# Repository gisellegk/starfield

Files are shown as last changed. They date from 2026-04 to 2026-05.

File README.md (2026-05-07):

# Starfield
May the force be with you

Arduino Libraries:
- [kriswiner/LP5036](https://github.com/kriswiner/LP5036/tree/master)
- [JackDaviesDesign/Pimoroni-11x7-LED-Matrix-Arduino](https://github.com/JackDaviesDesign/Pimoroni-11x7-LED-Matrix-Arduino)

Font:
- [Star Jedi](https://www.dafont.com/star-jedi.font)

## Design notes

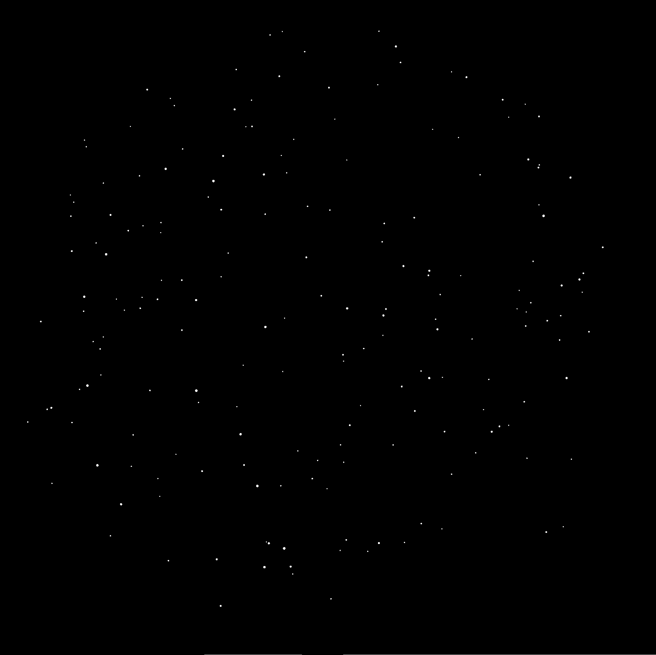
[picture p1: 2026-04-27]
stellarium-sc/dim_stars.png

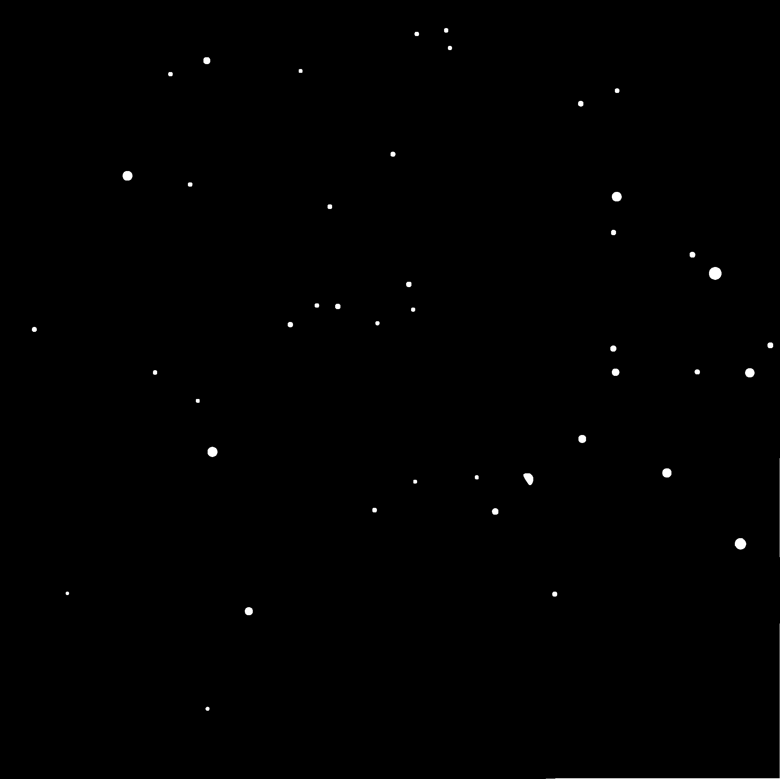
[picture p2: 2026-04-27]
stellarium-sc/bright.png

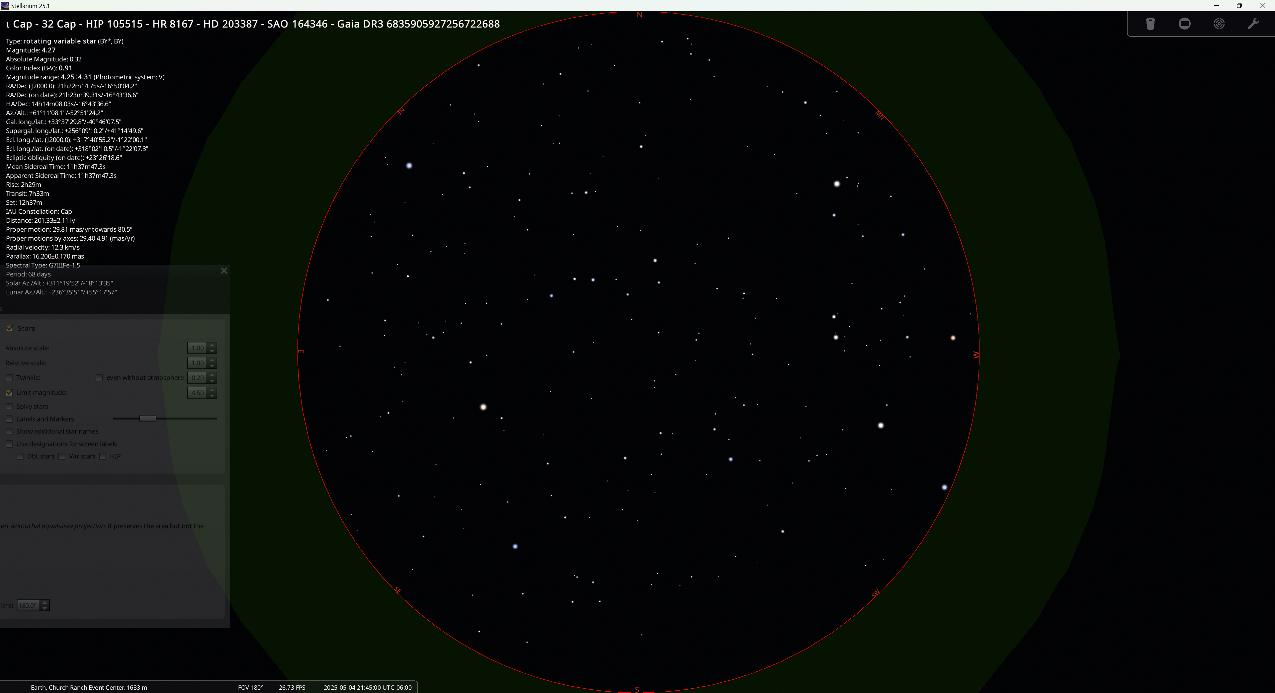
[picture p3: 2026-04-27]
stellarium-sc/4.5+.png

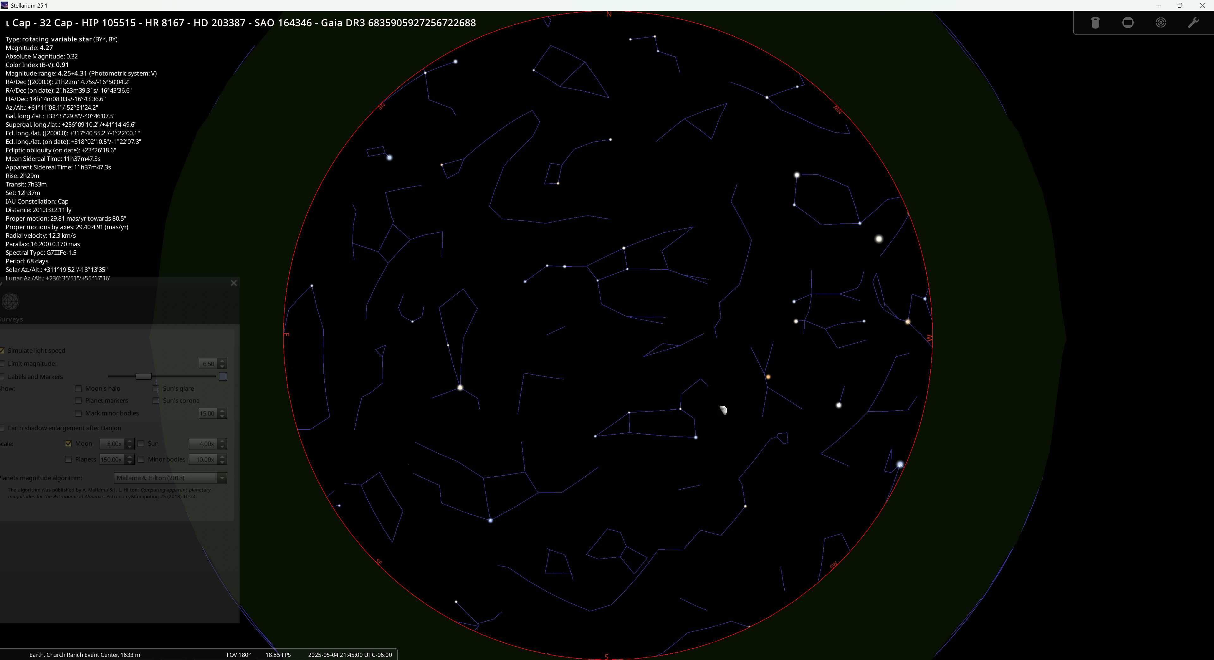
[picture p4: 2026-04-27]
stellarium-sc/lines.png

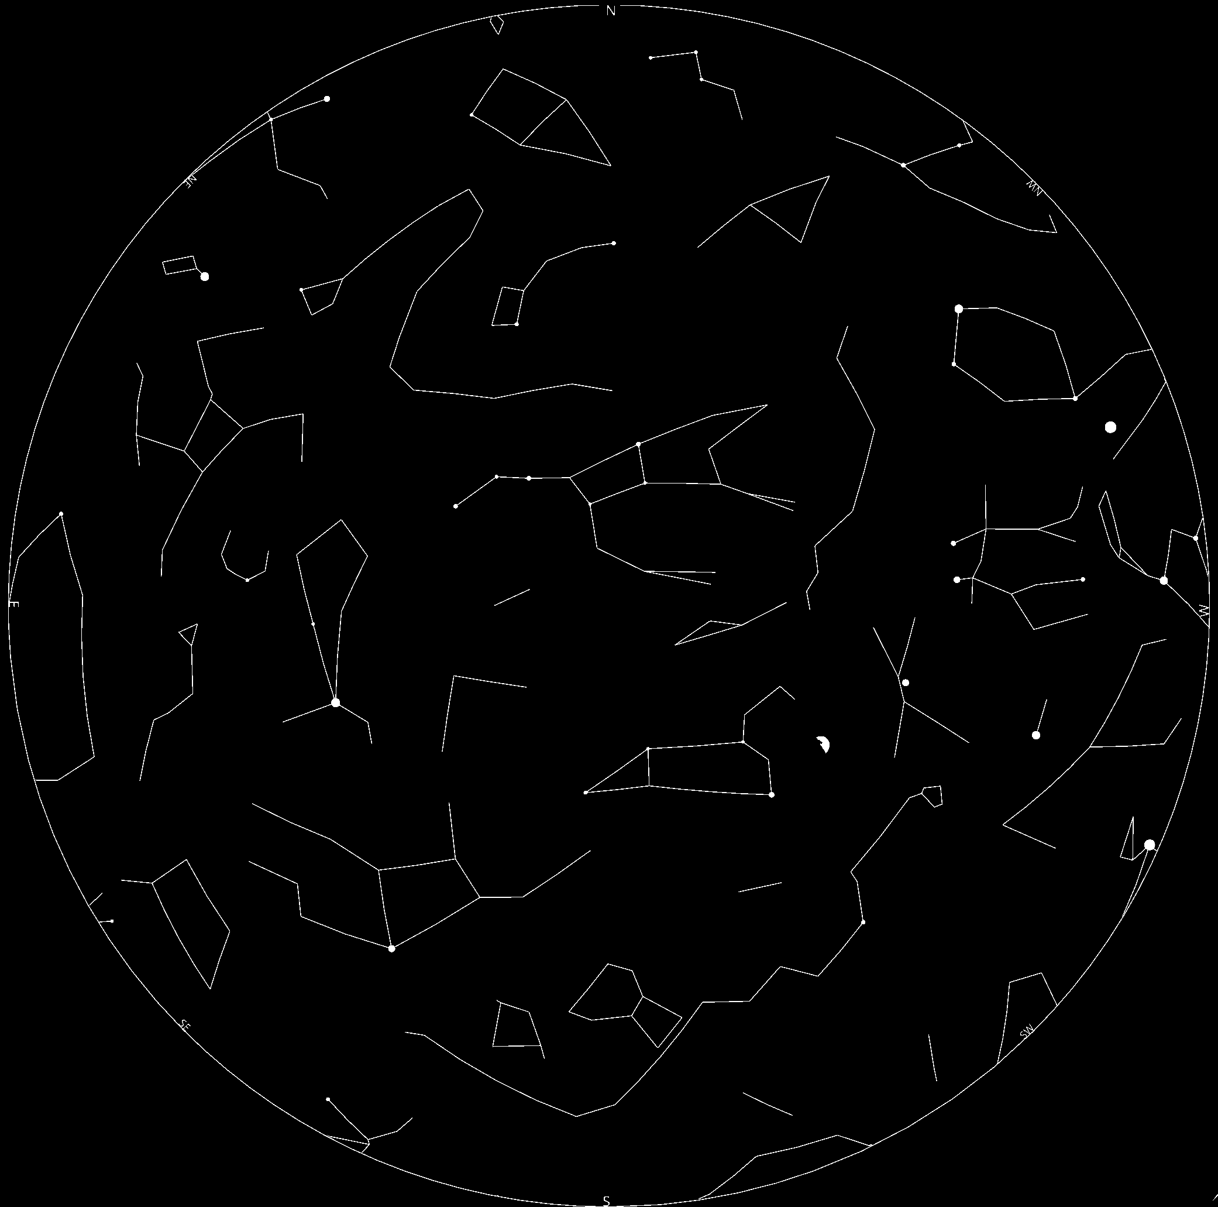
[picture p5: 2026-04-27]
stellarium-sc/lines-thresh.png

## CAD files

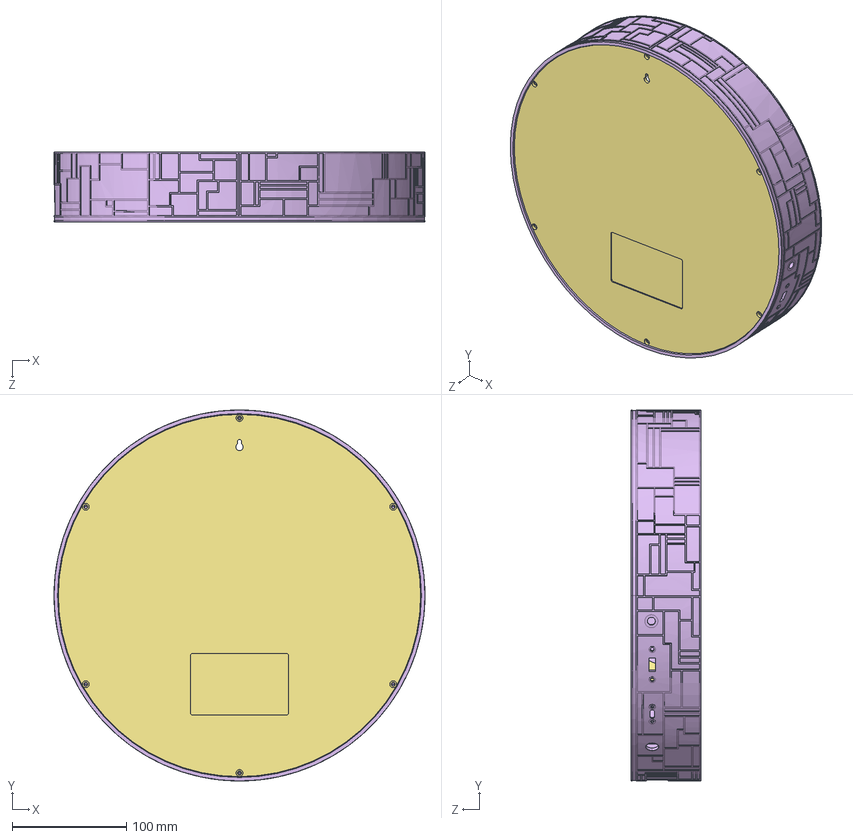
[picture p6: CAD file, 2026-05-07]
3D/FrameAssembly.STEP
325.1 x 325.1 x 61.6 mm
FrameFront
back
fiberholder
MoonInsert

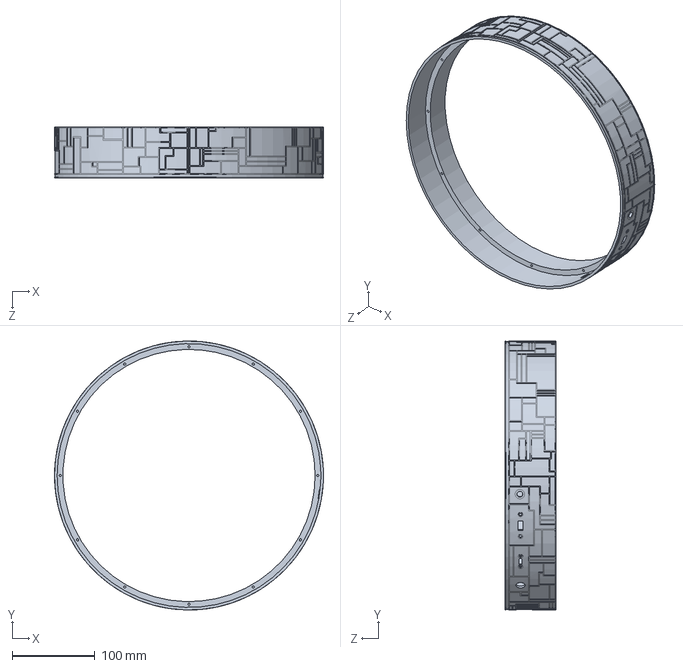
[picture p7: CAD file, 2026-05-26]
3D/FrameFront.SLDPRT
325.1 x 325.1 x 61.6 mm

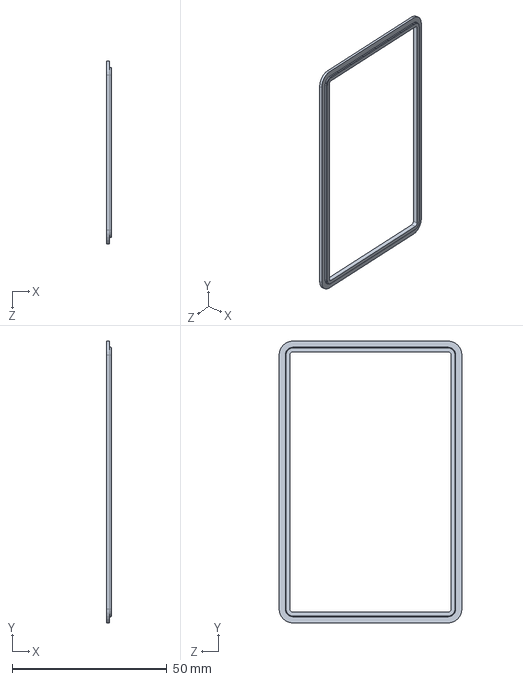
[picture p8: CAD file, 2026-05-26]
3D/CardFrame.SLDPRT
1.77 x 91.0 x 59.0 mm

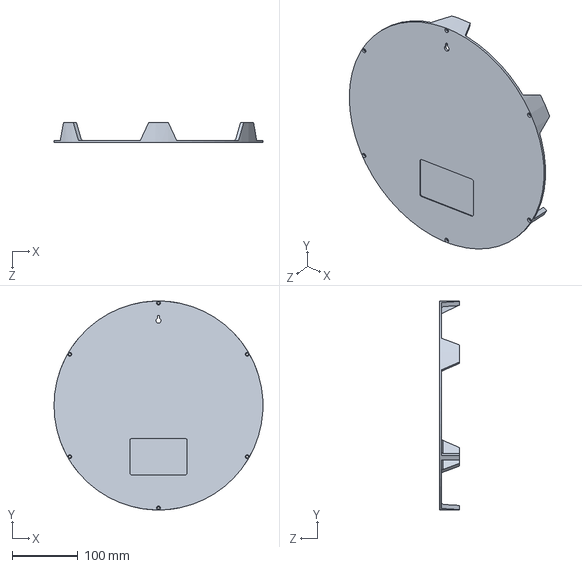
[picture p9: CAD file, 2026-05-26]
3D/back.SLDPRT
317.5 x 317.4 x 30.2 mm

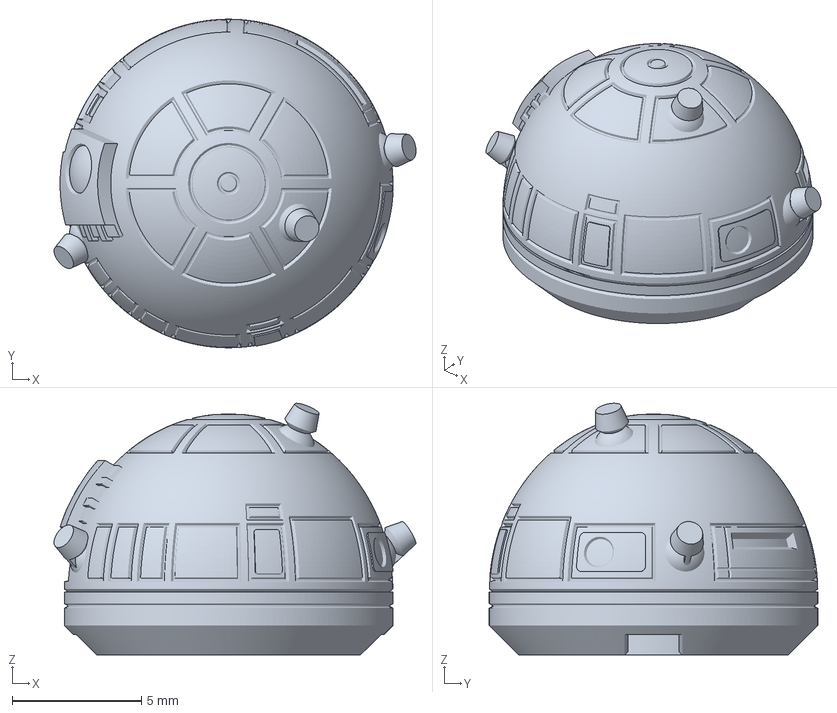
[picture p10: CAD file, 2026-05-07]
3D/R2D2Cap.3mf
14.0 x 12.7 x 9.73 mm

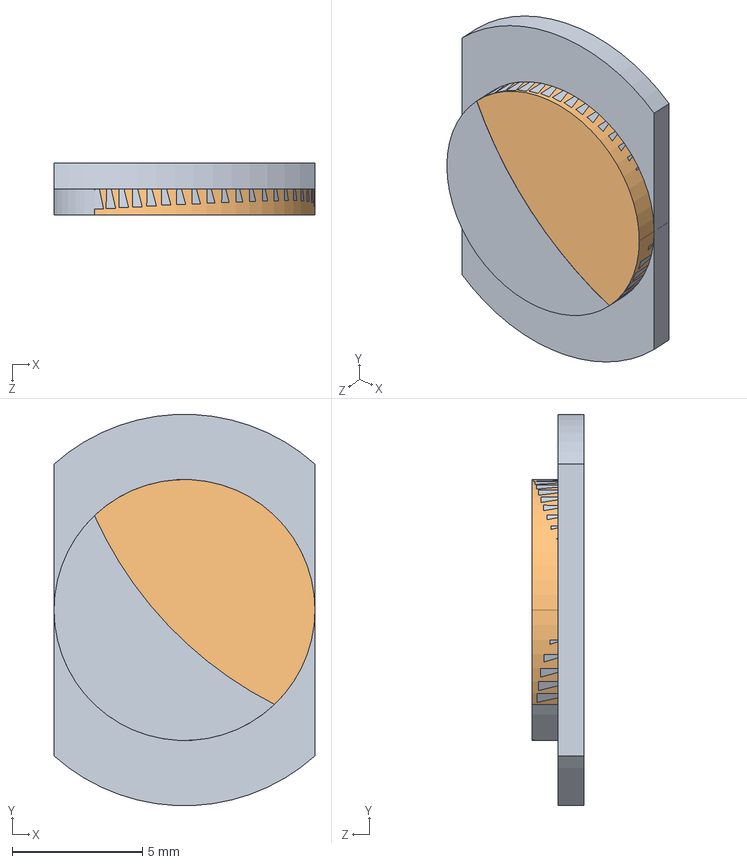
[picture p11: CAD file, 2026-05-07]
3D/MoonInsert.STEP
10.0 x 15.0 x 2.00 mm

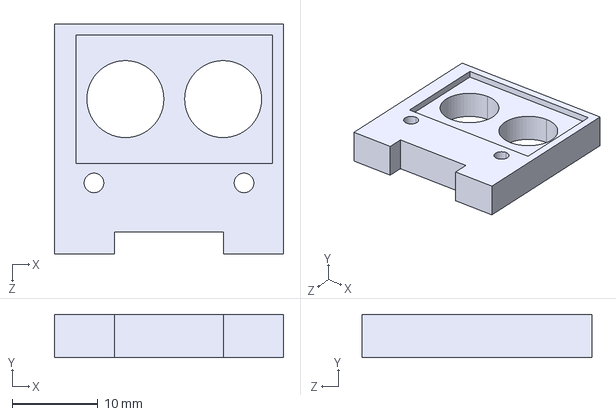
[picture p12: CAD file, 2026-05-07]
3D/FiberHolder.STEP
26.8 x 5.08 x 26.9 mm

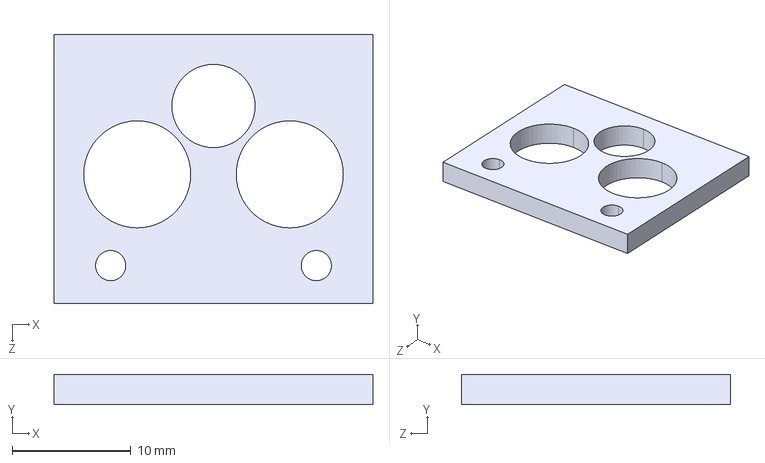
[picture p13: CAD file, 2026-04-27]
3D/fiber-optic-mount.STEP
26.8 x 2.54 x 22.6 mm

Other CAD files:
3D/FrameBack.STEP
3D/FrameAssembly.3mf
3D/FrameAssembly.SLDASM
3D/FrameFront.STL
3D/MoonInsert.SLDPRT
3D/fiberholder.SLDPRT

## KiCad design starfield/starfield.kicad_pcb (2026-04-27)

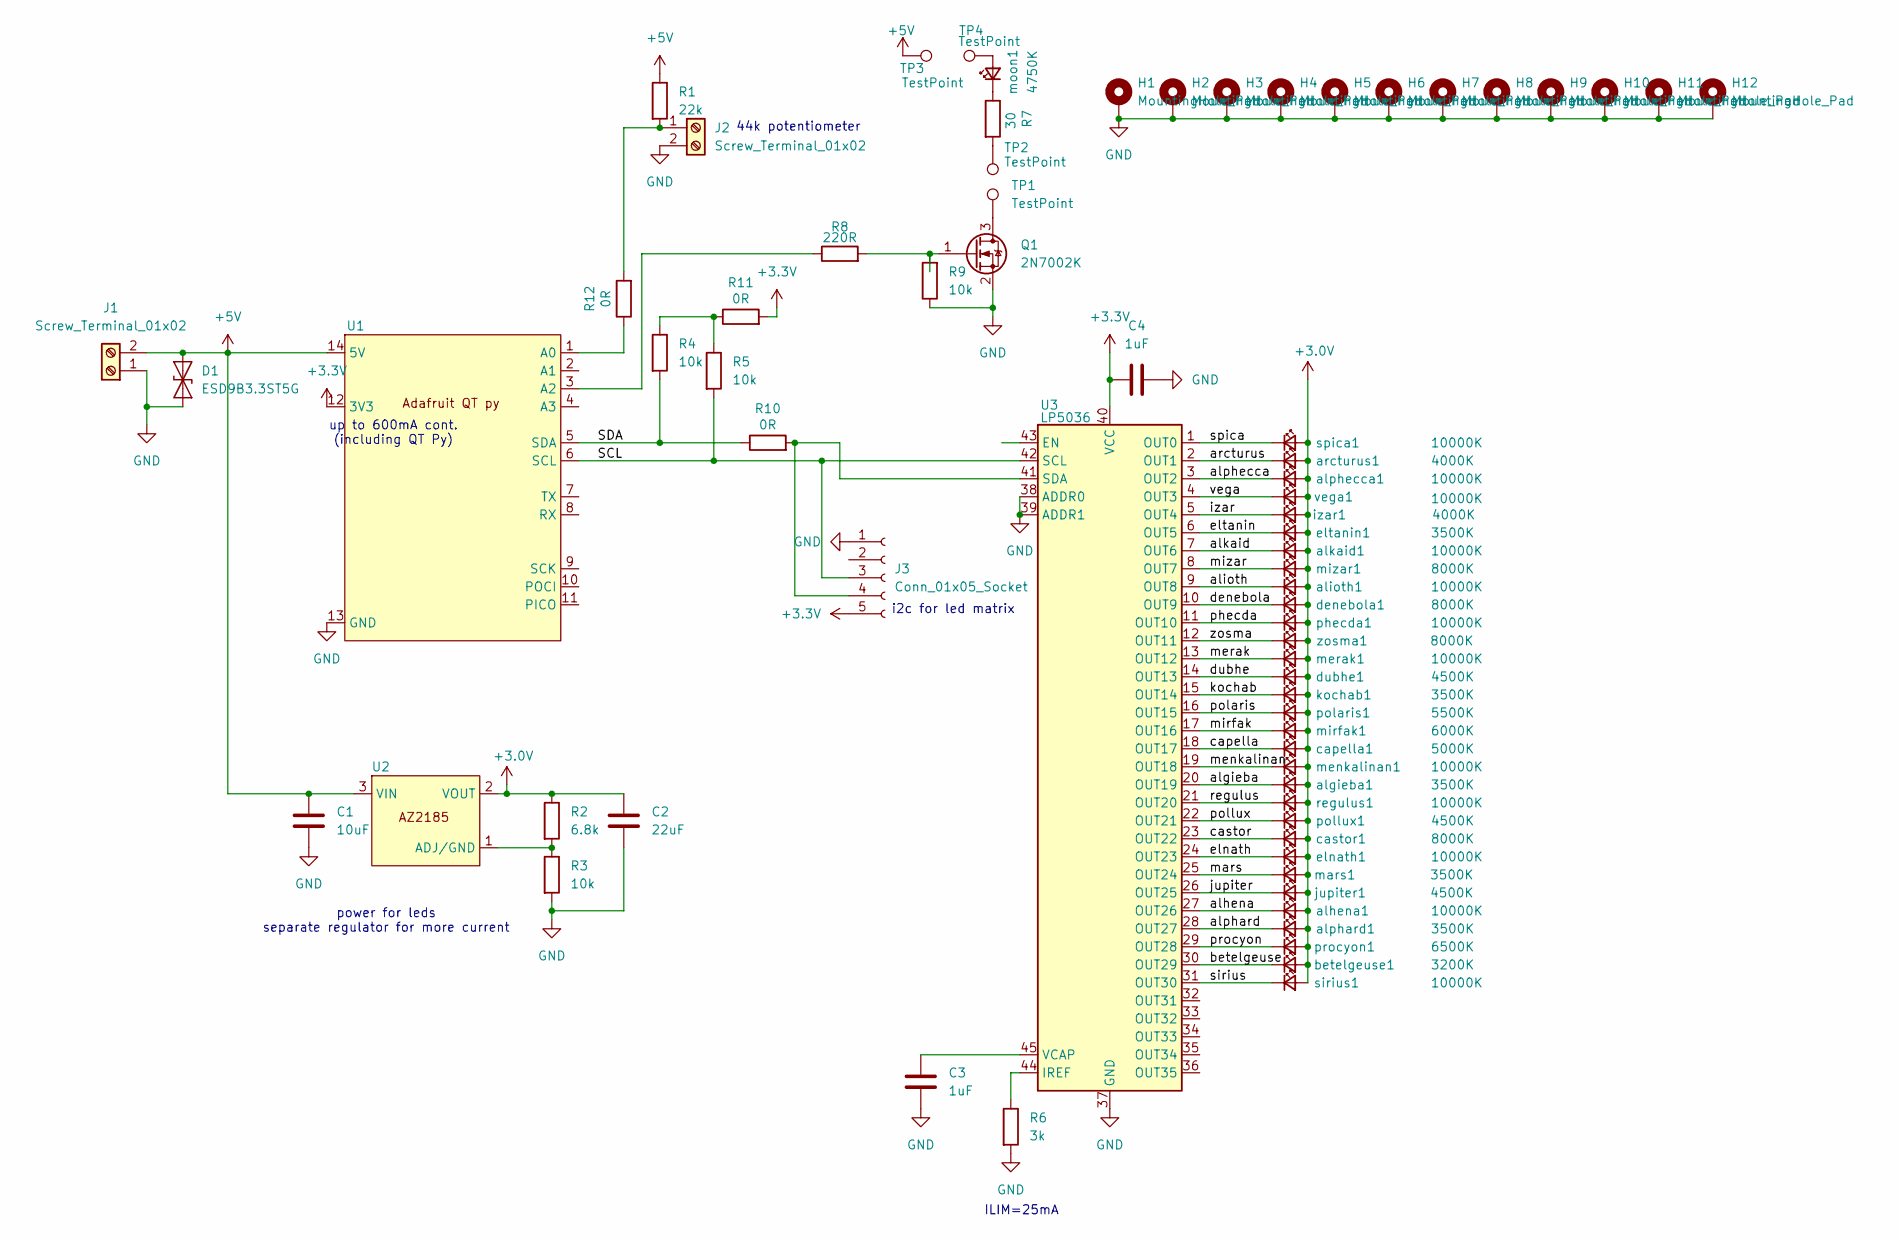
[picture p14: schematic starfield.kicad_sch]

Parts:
C1: 10uF; C_0402_1005Metric
C2: 22uF; C_0402_1005Metric
C3, C4: 1uF; C_0402_1005Metric
D1: ESD9B3.3ST5G; D_SOD-923
H1, H2, H3, H4, H5, H6, H7, H8, H9, H10, H11, H12: MountingHole_Pad; MountingHole_3.2mm_M3
J1, J2: Screw_Terminal_01x02; TBLH11-350-02BK
J3: Conn_01x05_Socket; M207910542R
Q1: 2N7002K; SOT-23
R1: 22k; R_0402_1005Metric
R2: 6.8k; R_0402_1005Metric
R3, R4, R5, R9: 10k; R_0402_1005Metric
R6: 3k; R_0402_1005Metric
R7: 30; R_0805_2012Metric
R8: 220R; R_0402_1005Metric
R10, R11, R12: 0R; R_1206_3216Metric
TP1, TP2, TP3, TP4: TestPoint; TestPoint_Keystone_5015_Micro_Mini
U1: XIAO-SAMD21-SMD
U2: AZ2185
U3: LP5036; VQFN-46-1EP_5x6mm_P0.4mm_EP2.8x3.8mm
algieba1: 3500K; ASMY-CWG0-Nxxx2-revmnt
alhena1: 10000K; LUXEON-3014-revmnt
alioth1: 10000K; LUXEON-3014-revmnt
alkaid1: 10000K; LUXEON-3014-revmnt
alphard1: 3500K; ASMY-CWG0-Nxxx2-revmnt
alphecca1: 10000K; LUXEON-3014-revmnt
arcturus1: 4000K; ASMY-CWG0-Nxxx2-revmnt
betelgeuse1: 3200K; ASMY-CWG0-Nxxx2-revmnt
capella1: 5000K; ASMY-CWG0-Nxxx2-revmnt
castor1: 8000K; ASMY-CWG0-Nxxx2-revmnt
denebola1: 8000K; ASMY-CWG0-Nxxx2-revmnt
dubhe1: 4500K; ASMY-CWG0-Nxxx2-revmnt
elnath1: 10000K; LUXEON-3014-revmnt
eltanin1: 3500K; ASMY-CWG0-Nxxx2-revmnt
izar1: 4000K; ASMY-CWG0-Nxxx2-revmnt
jupiter1: 4500K; ASMY-CWG0-Nxxx2-revmnt
kochab1: 3500K; ASMY-CWG0-Nxxx2-revmnt
mars1: 3500K; ASMY-CWG0-Nxxx2-revmnt
menkalinan1: 10000K; LUXEON-3014-revmnt
merak1: 10000K; LUXEON-3014-revmnt
mirfak1: 6000K; WL-SWTP-revmnt
mizar1: 8000K; ASMY-CWG0-Nxxx2-revmnt
moon1: 4750K; moon
phecda1: 10000K; LUXEON-3014-revmnt
polaris1: 5500K; ASMY-CWG0-Nxxx2-revmnt
pollux1: 4500K; ASMY-CWG0-Nxxx2-revmnt
procyon1: 6500K; ASMY-CWG0-Nxxx2-revmnt
regulus1: 10000K; LUXEON-3014-revmnt
sirius1: 10000K; LUXEON-3014-revmnt
spica1: 10000K; LUXEON-3014-revmnt
vega1: 10000K; LUXEON-3014-revmnt
zosma1: 8000K; ASMY-CWG0-Nxxx2-revmnt

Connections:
+3.0V: C2.1, R2.1, U2.2 (VOUT), algieba1.2 (A), alhena1.2 (A), alioth1.2 (A), alkaid1.2 (A), alphard1.2 (A), alphecca1.2 (A), arcturus1.2 (A), betelgeuse1.2 (A), capella1.2 (A), castor1.2 (A), denebola1.2 (A), dubhe1.2 (A), elnath1.2 (A), eltanin1.2 (A), izar1.2 (A), jupiter1.2 (A), kochab1.2 (A), mars1.2 (A), menkalinan1.2 (A), merak1.2 (A), mirfak1.2 (A), mizar1.2 (A), phecda1.2 (A), polaris1.2 (A), pollux1.2 (A), procyon1.2 (A), regulus1.2 (A), sirius1.2 (A), spica1.2 (A), vega1.2 (A), zosma1.2 (A)
+3.3V: C4.1, J3.5, R11.2, U1.12 (3V3), U3.40 (VCC)
+5V: C1.1, D1.1 (A1), J1.2, R1.1, TP3.1, U1.14 (5V), U2.3 (VIN)
/SCL: J3.3, R5.2, U1.6 (SCL), U3.42 (SCL)
/SDA: R4.2, R10.1, U1.5 (SDA)
/algieba: U3.20 (OUT19), algieba1.1 (K)
/alhena: U3.27 (OUT26), alhena1.1 (K)
/alioth: U3.9 (OUT8), alioth1.1 (K)
/alkaid: U3.7 (OUT6), alkaid1.1 (K)
/alphard: U3.28 (OUT27), alphard1.1 (K)
/alphecca: U3.3 (OUT2), alphecca1.1 (K)
/arcturus: U3.2 (OUT1), arcturus1.1 (K)
/betelgeuse: U3.30 (OUT29), betelgeuse1.1 (K)
/capella: U3.18 (OUT17), capella1.1 (K)
/castor: U3.23 (OUT22), castor1.1 (K)
/denebola: U3.10 (OUT9), denebola1.1 (K)
/dubhe: U3.14 (OUT13), dubhe1.1 (K)
/elnath: U3.24 (OUT23), elnath1.1 (K)
/eltanin: U3.6 (OUT5), eltanin1.1 (K)
/izar: U3.5 (OUT4), izar1.1 (K)
/jupiter: U3.26 (OUT25), jupiter1.1 (K)
/kochab: U3.15 (OUT14), kochab1.1 (K)
/mars: U3.25 (OUT24), mars1.1 (K)
/menkalinan: U3.19 (OUT18), menkalinan1.1 (K)
/merak: U3.13 (OUT12), merak1.1 (K)
/mirfak: U3.17 (OUT16), mirfak1.1 (K)
/mizar: U3.8 (OUT7), mizar1.1 (K)
/phecda: U3.11 (OUT10), phecda1.1 (K)
/polaris: U3.16 (OUT15), polaris1.1 (K)
/pollux: U3.22 (OUT21), pollux1.1 (K)
/procyon: U3.29 (OUT28), procyon1.1 (K)
/regulus: U3.21 (OUT20), regulus1.1 (K)
/sirius: U3.31 (OUT30), sirius1.1 (K)
/spica: U3.1 (OUT0), spica1.1 (K)
/vega: U3.4 (OUT3), vega1.1 (K)
/zosma: U3.12 (OUT11), zosma1.1 (K)
GND: C1.2, C2.2, C3.2, C4.2, D1.2 (A2), H1.1, H2.1, H3.1, H4.1, H5.1, H6.1, H7.1, H8.1, H9.1, H10.1, H11.1, H12.1, J1.1, J2.2, J3.1, Q1.2 (S), R3.2, R6.2, R9.1, U1.13 (GND), U3.37 (GND), U3.38 (ADDR0), U3.39 (ADDR1), U3.46 (GND), U3.47 (GND)
unnamed: J2.1, R1.2, R12.2
unnamed: J3.4, R10.2, U3.41 (SDA)
unnamed: Q1.3 (D), TP1.1
unnamed: Q1.1 (G), R8.2, R9.2
unnamed: R7.2, TP2.1
unnamed: R4.1, R5.1, R11.1
unnamed: R12.1, U1.1 (A0)
unnamed: R8.1, U1.3 (A2)
unnamed: R2.2, R3.1, U2.1 (ADJ/GND)
unnamed: R6.1, U3.44 (IREF)
unnamed: C3.1, U3.45 (VCAP)
unnamed: TP4.1, moon1.2 (A)
unnamed: R7.1, moon1.1 (K)

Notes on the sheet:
power for leds separate regulator for more current
up to 600mA cont. (including QT Py)
i2c for led matrix
ILIM=25mA
44k potentiometer

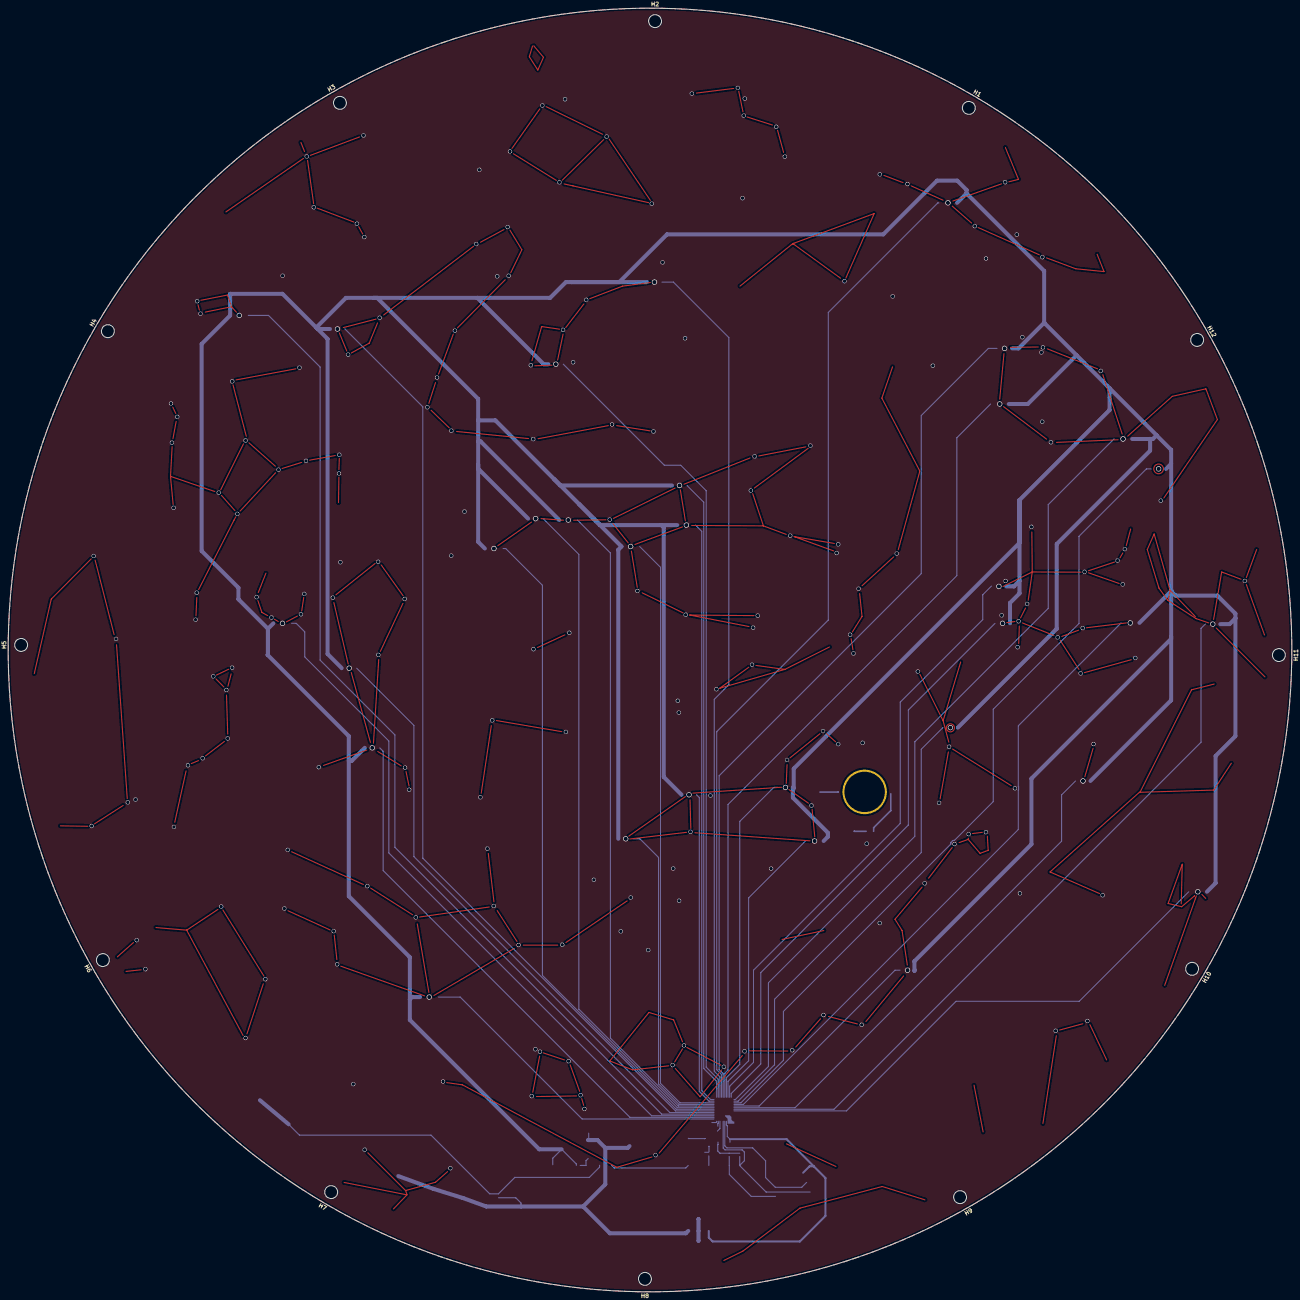
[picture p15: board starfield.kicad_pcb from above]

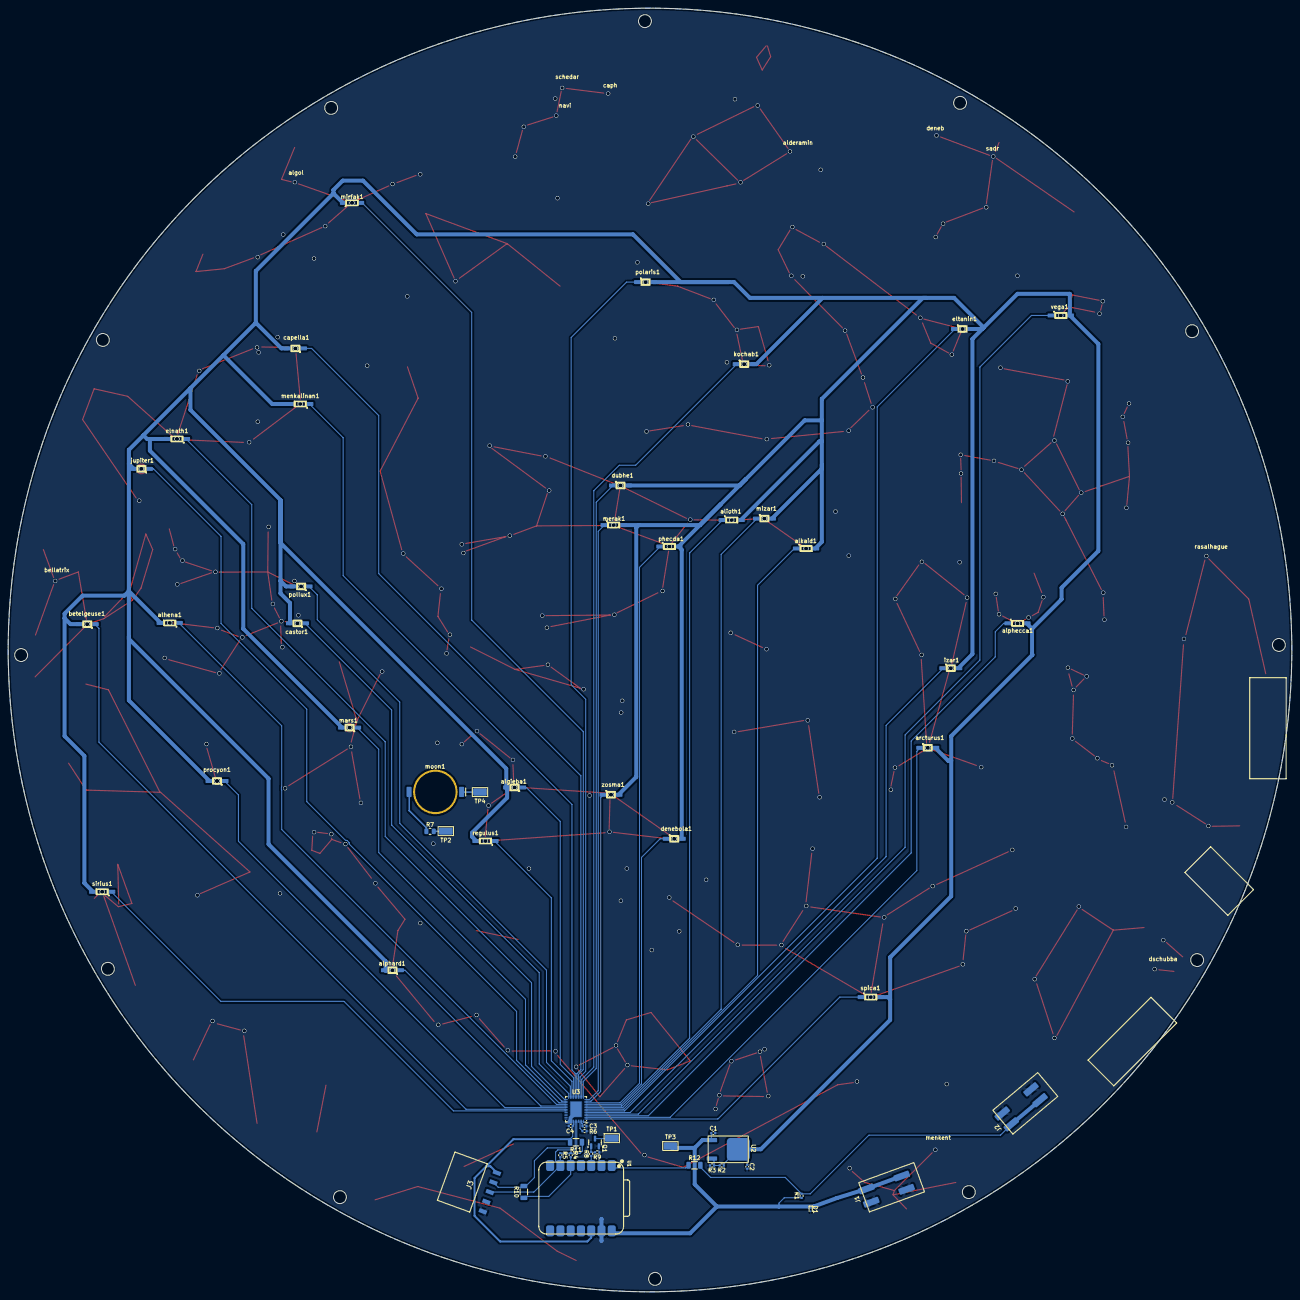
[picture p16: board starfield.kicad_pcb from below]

Board: 2 copper layers, 317.5 x 317.5 mm, 74 parts (60 on the bottom side), 50 nets.

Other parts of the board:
brights: LOGO
dims: LOGO

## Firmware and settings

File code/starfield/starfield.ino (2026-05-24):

#include <Wire.h>
#include "LED_11x7_Matrix_IS31FL3731.h"
#include "LP5036.h"


LED_11x7_Matrix_IS31FL3731 ledmatrix = LED_11x7_Matrix_IS31FL3731(); // create ledmatrix object

#define NUM_MATRIX_LEDS 77
#define MATRIX_X 7
#define MATRIX_Y 11

#define MATRIX_B_MAX 60
uint8_t b_matrix[MATRIX_X][MATRIX_Y];
uint8_t b_matrix_target[MATRIX_X][MATRIX_Y];

#define FRAME_CTR_MAX 30
uint8_t frame_ctr;

#define KNOB_PIN 0
double knob_val; // 0-1

#define MOON_PIN 2
uint8_t moon;

#define NC_PIN 3

LP5036 LP5036; // instantiate LP5036 class

#define NUM_B_STARS 36
const uint8_t base_b_stars[NUM_B_STARS] = 
{
  93, 161, 16, 134, 5, 12,
  44, 21, 49, 27, 8, 2,
  12, 48, 28, 30, 21, 144,
  34, 12, 71, 85, 58, 37,
  98, 255, 28, 31, 128, 89, 
  0, 0, 0, 0, 0, 106 

};

uint8_t b_stars[NUM_B_STARS] = 
{
  93, 161, 16, 134, 5, 12,
  44, 21, 49, 27, 8, 2,
  12, 48, 28, 30, 21, 144,
  34, 12, 71, 85, 58, 37,
  98, 255, 28, 31, 128, 89, 
  0, 0, 0, 0, 0, 106

};

uint8_t t_stars[NUM_B_STARS];


void setup() {
  Serial.begin(9600);
  
  randomSeed(analogRead(NC_PIN));

  // Matrix Setup
  if (! ledmatrix.begin()) {
    Serial.println("IS31 not found");
    // while (1);
  }
  Serial.println("IS31 Found!");
  ledmatrix.clear();

  // LP5036 setup
  // i2c already init in ledmatrix.begin()
  LP5036.I2Cscan();

  LP5036.powerUp();

  LP5036.init(); // set PWM frequency and output current for all leds

  LP5036.setRunMode();
  LP5036.bankControlOff(); // control each rgb led individually to test function

  // fade all in  
  frame_ctr = 0;
  moon = 0;
  read_knob();
  matrix_gen_target();
  bright_gen_target();

  uint8_t moon_target = pow(254, knob_val) +1;

  while(frame_ctr < FRAME_CTR_MAX){
    moon += moon_target/FRAME_CTR_MAX;
    analogWrite(MOON_PIN, moon);
    update_matrix_stars();
    update_bright_stars();
    frame_ctr++;
    delay(10);
  }

  // prep for loop
  matrix_gen_target();
  bright_gen_target();
  frame_ctr = 0;
}


void loop() {
  
  update_matrix_stars();
  update_bright_stars();
  update_moon();

  read_knob();
  frame_ctr++;
  if(frame_ctr >= FRAME_CTR_MAX){
    matrix_gen_target();
    bright_gen_target();
    frame_ctr = 0;
  }
  // delay(10);
}

void read_knob(){
  knob_val = analogRead(KNOB_PIN)/1023.0;
}

void update_moon(){
  // set brightness based on knob value
  moon = pow(200, knob_val) +1;
  analogWrite(MOON_PIN, moon);
}

void update_bright_stars(){
  uint8_t brightness = map(knob_val*100, 0,100, 20, 128);
  for(uint8_t ii = 0x00; ii < 12; ii++) {
    LP5036.setBrightness(ii, brightness);

    int d1 = t_stars[ii*3] - b_stars[ii*3];
    
    b_stars[ii*3] = b_stars[ii*3] + d1*frame_ctr/FRAME_CTR_MAX;
    LP5036.setColor(ii*3,   b_stars[ii*3]);
    // if(ii == 10) break;
    int d2 = t_stars[ii*3+1] - b_stars[ii*3+1];
    int d3 = t_stars[ii*3+2] - b_stars[ii*3+2];
    b_stars[ii*3+1] = b_stars[ii*3+1] + d2*frame_ctr/FRAME_CTR_MAX;
    b_stars[ii*3+2] = b_stars[ii*3+2] + d3*frame_ctr/FRAME_CTR_MAX;
    LP5036.setColor(ii*3+1, b_stars[ii*3+1]);
    LP5036.setColor(ii*3+2, b_stars[ii*3+2]);
  }

}

void bright_gen_target(){
  for(int i = 0; i < NUM_B_STARS; i++){
    if(i == 24 || i == 25) t_stars[i] = b_stars[i]; // no twinkle for planets
    else {
      t_stars[i] = base_b_stars[i]*(random(30,100)/100.0);
      if(t_stars[i] < 2) t_stars[i] = 2;
    }
  }
}



void matrix_gen_target(){
  for(int x = 0; x < MATRIX_X; x++){
    for(int y = 0; y < MATRIX_Y; y++){
      if(random(0,100) < (30+20*knob_val)){
        b_matrix_target[x][y] = random(0,MATRIX_B_MAX); 
      } else {
        b_matrix_target[x][y] = 0;
      }

    }
  }
}

void update_matrix_stars(){
  for(int x = 0; x < MATRIX_X; x++){
      for(int y = 0; y < MATRIX_Y; y++){
        int difference = b_matrix_target[x][y]* (pow(2,knob_val)-.8) - b_matrix[x][y];
        b_matrix[x][y] = b_matrix[x][y] + difference*frame_ctr/FRAME_CTR_MAX;
        // ledmatrix.drawPixel(x, y, b_matrix[x][y]);
      }
    }
    matrix_show();
}

void matrix_show(){
  for (uint8_t x=0; x<MATRIX_X; x++) {
    for (uint8_t y=0; y<MATRIX_Y; y++) {
      ledmatrix.drawPixel(x, y, b_matrix[x][y]);
    }
  } 
}

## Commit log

2026-04-27 3d files
    [FrameFront.SLDPRT, FrameFront.STL, Part1.SLDPRT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]
2026-04-27 kicad files
    [starfield.kicad_pcb, starfield.kicad_sch]
2026-05-01 update 3d files
    [FrameFront.SLDPRT, back.SLDPRT]
2026-05-03 Add final frame cad
    [FrameAssembly.3mf, FrameAssembly.STEP, FrameFront.SLDPRT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]
2026-05-03 Fix bedleveling code to not probe all the way back
    [FrameAssembly.3mf]
2026-05-07 Add final cad
    [FiberHolder.STEP, FrameAssembly.3mf, FrameAssembly.SLDASM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]
2026-05-26 Add frame
    [CardFrame.SLDPRT, FrameAssembly.3mf, FrameAssembly.SLDASM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]
